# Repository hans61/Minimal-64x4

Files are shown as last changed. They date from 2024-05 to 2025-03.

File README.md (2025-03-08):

# MY Games for the Minimal 64x4

My converted games from Minimal 64
The games 2048, sokoban, loderunner and atomix were automatically generated from the Minimal64 sources.

## Notice

I separated the hardware and software. The hardware can now be found here:
https://github.com/hans61/Minimal-64x4-Expansion

The Minimal 64x4 Home Computer by Slu4 can be found here:
https://github.com/slu4coder/Minimal-64x4-Home-Computer

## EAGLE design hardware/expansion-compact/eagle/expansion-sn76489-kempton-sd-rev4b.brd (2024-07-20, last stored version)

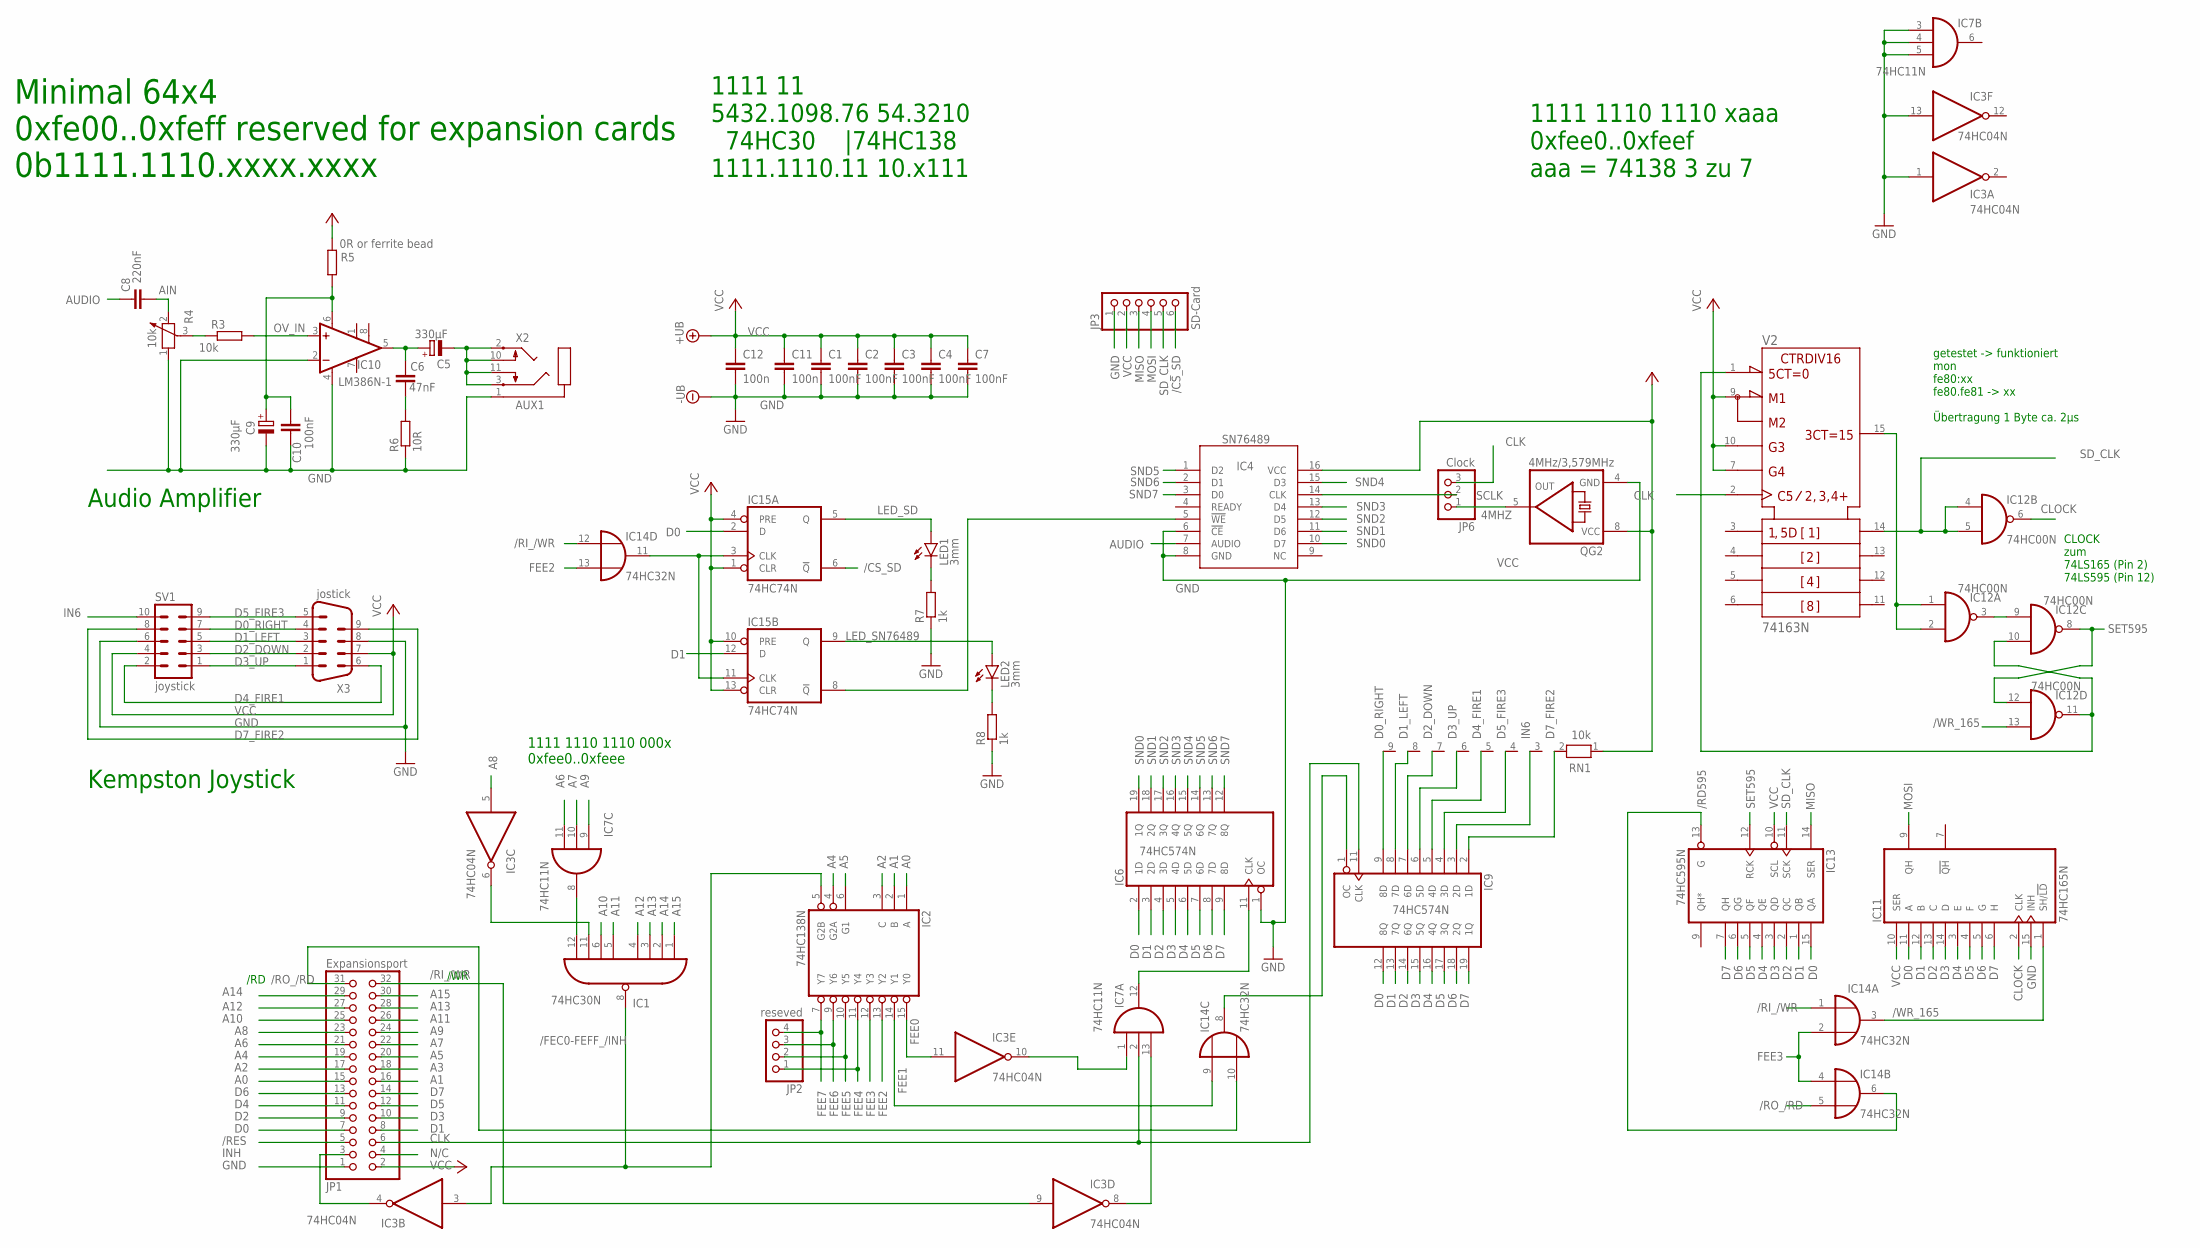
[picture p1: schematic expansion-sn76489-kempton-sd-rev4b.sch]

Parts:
C1, C2, C3, C4, C7, C10: 100nF; C050-025X075
C5, C9: 330µF; E2,5-7
C6: 47nF; C050-025X075
C8: 220nF; C050-025X075
C11, C12: 100n; C050-025X075
IC1: 74HC30N; DIL14
IC2: 74HC138N; DIL16
IC3: 74HC04N; DIL14
IC4: SN76489; ALEX-PARTS_DIL16
IC6, IC9: 74HC574N; DIL20
IC7: 74HC11N; DIL14
IC10: LM386N-1; DIL08
IC11: 74HC165N; DIL16
IC12: 74HC00N; DIL14
IC13: 74HC595N; DIL16
IC14: 74HC32N; DIL14
IC15: 74HC74N; DIL14
JP1: Expansionsport; 2X16
JP2: reseved; 1X04
JP3: SD-Card; 1X06
JP6: Clock; 1X03
LED1, LED2: 3mm; LED3MM
QG2: 4MHz/3,579MHz; DIL08S
R3: 10k; 0207/10
R4: 10k; PT-10S
R5: 0R or ferrite bead; 0207/10
R6: 10R; 0207/10
R7, R8: 1k; 0207/10
RN1: 10k; RN-9
SV1: joystick; ML10
V2: 74163N; DIL16
X2: AUX1; SJ1-352XN
X3: jostick; 182-009-MALE

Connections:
4MHZ: JP6.1, QG2.5 (OUT)
/CS_SD: IC15.6 (!Q), JP3.6
/FEC0-FEFF_/INH: IC1.8 (O), IC2.5 (G2B), IC3.3 (I)
/RD595: IC13.13 (G), IC14.6 (O)
/RES: JP1.5
/RI_/WR: IC3.9 (I), IC14.1 (I0), IC14.12 (I0), JP1.32
/RO_/RD: IC14.5 (I1), IC14.10 (I1), JP1.31
/WR_165: IC11.1 (SH/!LD), IC12.13 (I1), IC14.3 (O)
A0: IC2.1 (A), JP1.15
A1: IC2.2 (B), JP1.16
A2: IC2.3 (C), JP1.17
A3: JP1.18
A4: IC2.4 (G2A), JP1.19
A5: IC2.6 (G1), JP1.20
A6: IC7.11 (I2), JP1.21
A7: IC7.10 (I1), JP1.22
A8: IC3.5 (I), JP1.23
A9: IC7.9 (I0), JP1.24
A10: IC1.6 (I5), JP1.25
A11: IC1.5 (I4), JP1.26
A12: IC1.4 (I3), JP1.27
A13: IC1.3 (I2), JP1.28
A14: IC1.2 (I1), JP1.29
A15: IC1.1 (I0), JP1.30
AIN: C8.2, R4.2
AUDIO: C8.1, IC4.7 (AUDIO)
AUXOUT1: C5.-, X2.2, X2.3, X2.10, X2.11
AVCC: C9.+, C10.1, IC10.6 (VS), R5.1
CLK: IC7.2 (I1), IC9.11 (CLK), JP1.6, JP6.3, V2.2 (CLK)
CLOCK: IC11.2 (CLK), IC12.6 (O)
D0: IC6.2 (1D), IC9.12 (8Q), IC11.11 (A), IC13.15 (QA), IC15.2 (D), JP1.7
D0_RIGHT: IC9.9 (8D), RN1.9, SV1.7, X3.4
D1: IC6.3 (2D), IC9.13 (7Q), IC11.12 (B), IC13.1 (QB), IC15.12 (D), JP1.8
D1_LEFT: IC9.8 (7D), RN1.8, SV1.5, X3.3
D2: IC6.4 (3D), IC9.14 (6Q), IC11.13 (C), IC13.2 (QC), JP1.9
D2_DOWN: IC9.7 (6D), RN1.7, SV1.3, X3.2
D3: IC6.5 (4D), IC9.15 (5Q), IC11.14 (D), IC13.3 (QD), JP1.10
D3_UP: IC9.6 (5D), RN1.6, SV1.1, X3.1
D4: IC6.6 (5D), IC9.16 (4Q), IC11.3 (E), IC13.4 (QE), JP1.11
D4_FIRE1: IC9.5 (4D), RN1.5, SV1.2, X3.6
D5: IC6.7 (6D), IC9.17 (3Q), IC11.4 (F), IC13.5 (QF), JP1.12
D5_FIRE3: IC9.4 (3D), RN1.4, SV1.9, X3.5
D6: IC6.8 (7D), IC9.18 (2Q), IC11.5 (G), IC13.6 (QG), JP1.13
D7: IC6.9 (8D), IC9.19 (1Q), IC11.6 (H), IC13.7 (QH), JP1.14
D7_FIRE2: IC9.2 (1D), RN1.2, SV1.8, X3.9
FEE0: IC2.15 (Y0), IC3.11 (I)
FEE1: IC2.14 (Y1), IC14.9 (I0)
FEE2: IC2.13 (Y2), IC14.13 (I1)
FEE3: IC2.12 (Y3), IC14.2 (I1), IC14.4 (I0)
FEE4: IC2.11 (Y4), JP2.1
FEE5: IC2.10 (Y5), JP2.2
FEE6: IC2.9 (Y6), JP2.3
FEE7: IC2.7 (Y7), JP2.4
GND: C1.2, C2.2, C3.2, C4.2, C7.2, C9.-, C10.2, C11.2, C12.2, IC1.7 (GND), IC2.8 (GND), IC3.1 (I), IC3.7 (GND), IC3.13 (I), IC4.6 (!CE), IC4.8 (GND), IC6.1 (OC), IC6.10 (GND), IC7.3 (I0), IC7.4 (I1), IC7.5 (I2), IC7.7 (GND), IC9.10 (GND), IC10.2 (-IN), IC10.4 (GND), IC11.8 (GND), IC11.15 (INH), IC12.7 (GND), IC13.8 (GND), IC14.7 (GND), IC15.7 (GND), JP1.1, JP3.1, QG2.4 (GND), R4.1, R6.1, R7.1, R8.1, SV1.6, V2.8 (-UB), X2.1, X3.8
IN6: IC9.3 (2D), RN1.3, SV1.10
INH: IC3.4 (O), JP1.3
INPUT_EN: IC9.1 (OC), IC14.8 (O)
LED_SD: IC15.5 (Q), LED1.A
LED_SN76489: IC15.9 (Q), LED2.A
MISO: IC13.14 (SER), JP3.3
MOSI: IC11.9 (QH), JP3.4
unnamed: LED2.K (C), R8.2
unnamed: IC3.10 (O), IC7.1 (I0)
unnamed: IC1.12 (I7), IC7.8 (O)
unnamed: C6.2, R6.2
unnamed: IC12.1 (I0), IC12.2 (I1), V2.15 (RCO)
unnamed: R3.1, R4.3
unnamed: IC12.10 (I1), IC12.11 (O), V2.1 (!CLR)
unnamed: IC12.3 (O), IC12.9 (I0)
unnamed: IC14.11 (O), IC15.3 (CLK), IC15.11 (CLK)
unnamed: LED1.K (C), R7.2
unnamed: IC4.5 (!WE), IC15.8 (!Q)
unnamed: IC1.11 (I6), IC3.6 (O)
N/C: JP1.4
OV_IN: IC10.3 (+IN), R3.2
R2C2C3: C5.+, C6.1, IC10.5 (OUT)
RI_WR: IC3.8 (O), IC7.13 (I2)
SCLK: IC4.14 (CLK), JP6.2
SD_CLK: IC12.4 (I0), IC12.5 (I1), IC13.11 (SCK), JP3.5, V2.14 (QA)
SET595: IC12.8 (O), IC12.12 (I0), IC13.12 (RCK)
SND0: IC4.10 (D7), IC6.19 (1Q)
SND1: IC4.11 (D6), IC6.18 (2Q)
SND2: IC4.12 (D5), IC6.17 (3Q)
SND3: IC4.13 (D4), IC6.16 (4Q)
SND4: IC4.15 (D3), IC6.15 (5Q)
SND5: IC4.1 (D2), IC6.14 (6Q)
SND6: IC4.2 (D1), IC6.13 (7Q)
SND7: IC4.3 (D0), IC6.12 (8Q)
SOUND_EN: IC6.11 (CLK), IC7.12 (O)
VCC: C1.1, C2.1, C3.1, C4.1, C7.1, C11.1, C12.1, IC1.14 (VCC), IC2.16 (VCC), IC3.14 (VCC), IC4.16 (VCC), IC6.20 (VCC), IC7.14 (VCC), IC9.20 (VCC), IC11.10 (SER), IC11.16 (VCC), IC12.14 (VCC), IC13.10 (SCL), IC13.16 (VCC), IC14.14 (VCC), IC15.1 (CLR), IC15.4 (PRE), IC15.10 (PRE), IC15.13 (CLR), IC15.14 (VCC), JP1.2, JP3.2, QG2.8 (VCC), R5.2, RN1.1, SV1.4, V2.7 (ENP), V2.9 (!LOAD), V2.10 (ENT), V2.16 (+UB), X3.7

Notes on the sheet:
1111 1110 1110 xaaa 0xfee0..0xfeef aaa = 74138 3 zu 7
1111 1110 1110 000x 0xfee0..0xfeee
/WR
/RD
Minimal 64x4 0xfe00..0xfeff reserved for expansion cards 0b1111.1110.xxxx.xxxx
1111 11 5432.1098.76 54.3210 74HC30 |74HC138 1111.1110.11 10.x111
Kempston Joystick
Audio Amplifier
CLOCK zum 74LS165 (Pin 2) 74LS595 (Pin 12)
getestet -> funktioniert mon fe80:xx fe80.fe81 -> xx Übertragung 1 Byte ca. 2µs

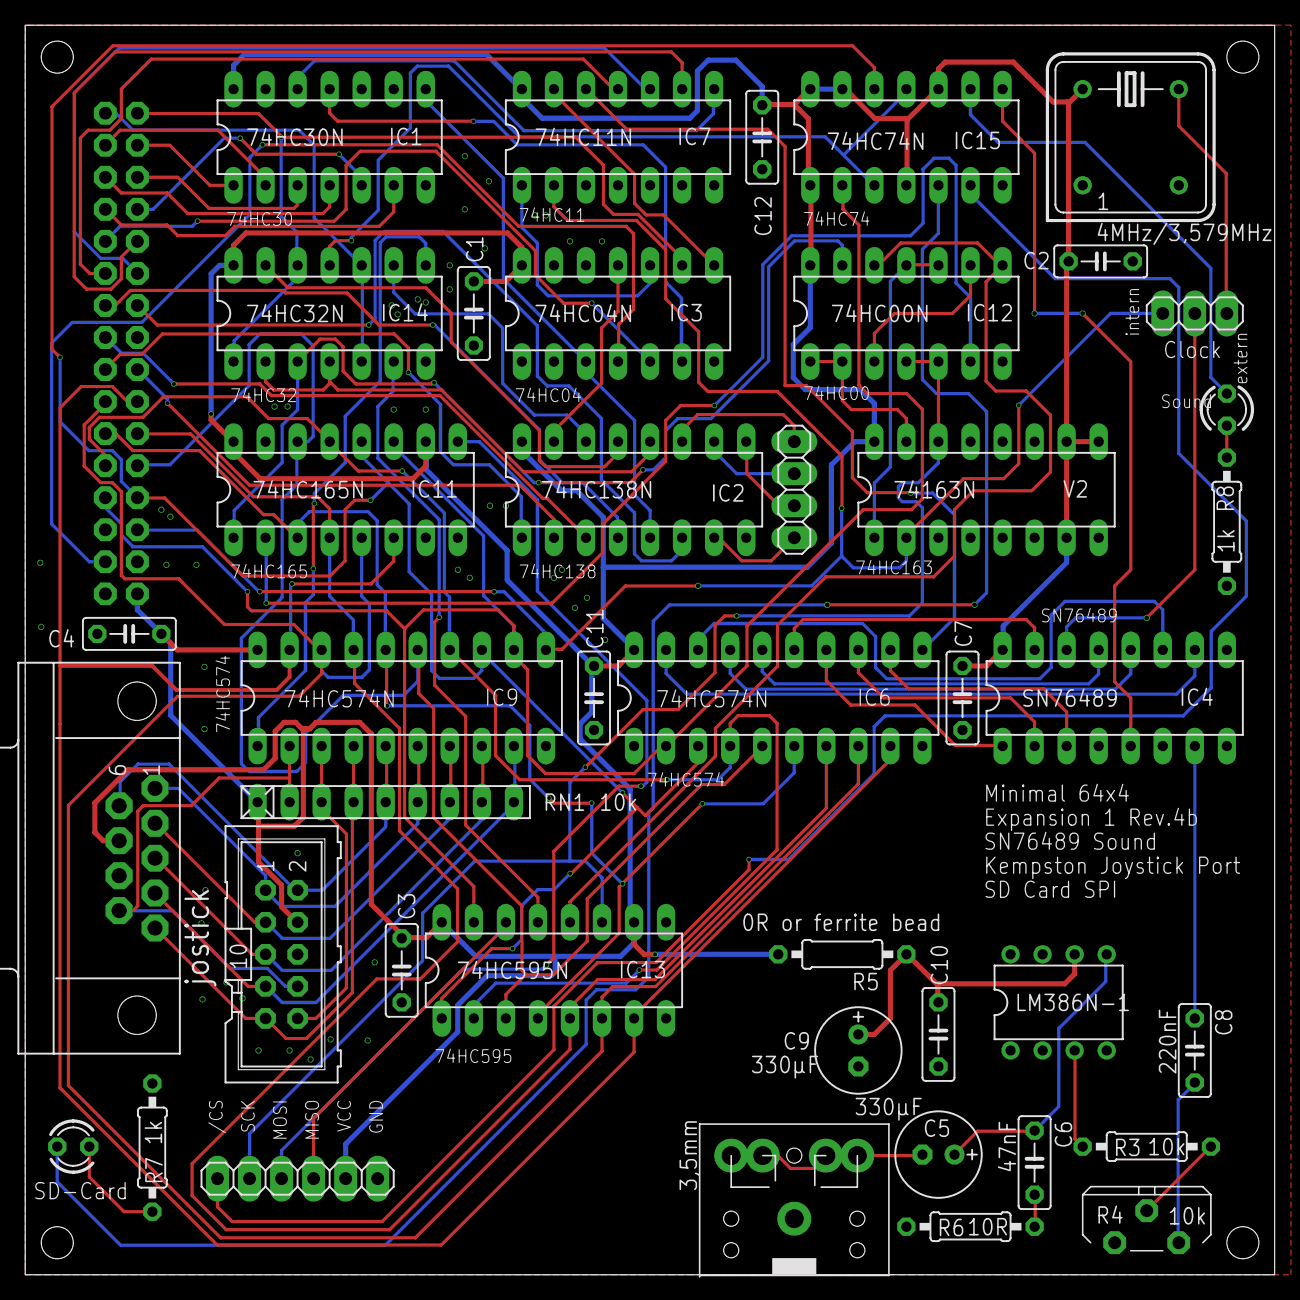
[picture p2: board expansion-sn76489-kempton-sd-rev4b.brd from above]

Board: 2 copper layers, 99.0 x 99.0 mm, 43 parts (1 on the bottom side), 87 nets.

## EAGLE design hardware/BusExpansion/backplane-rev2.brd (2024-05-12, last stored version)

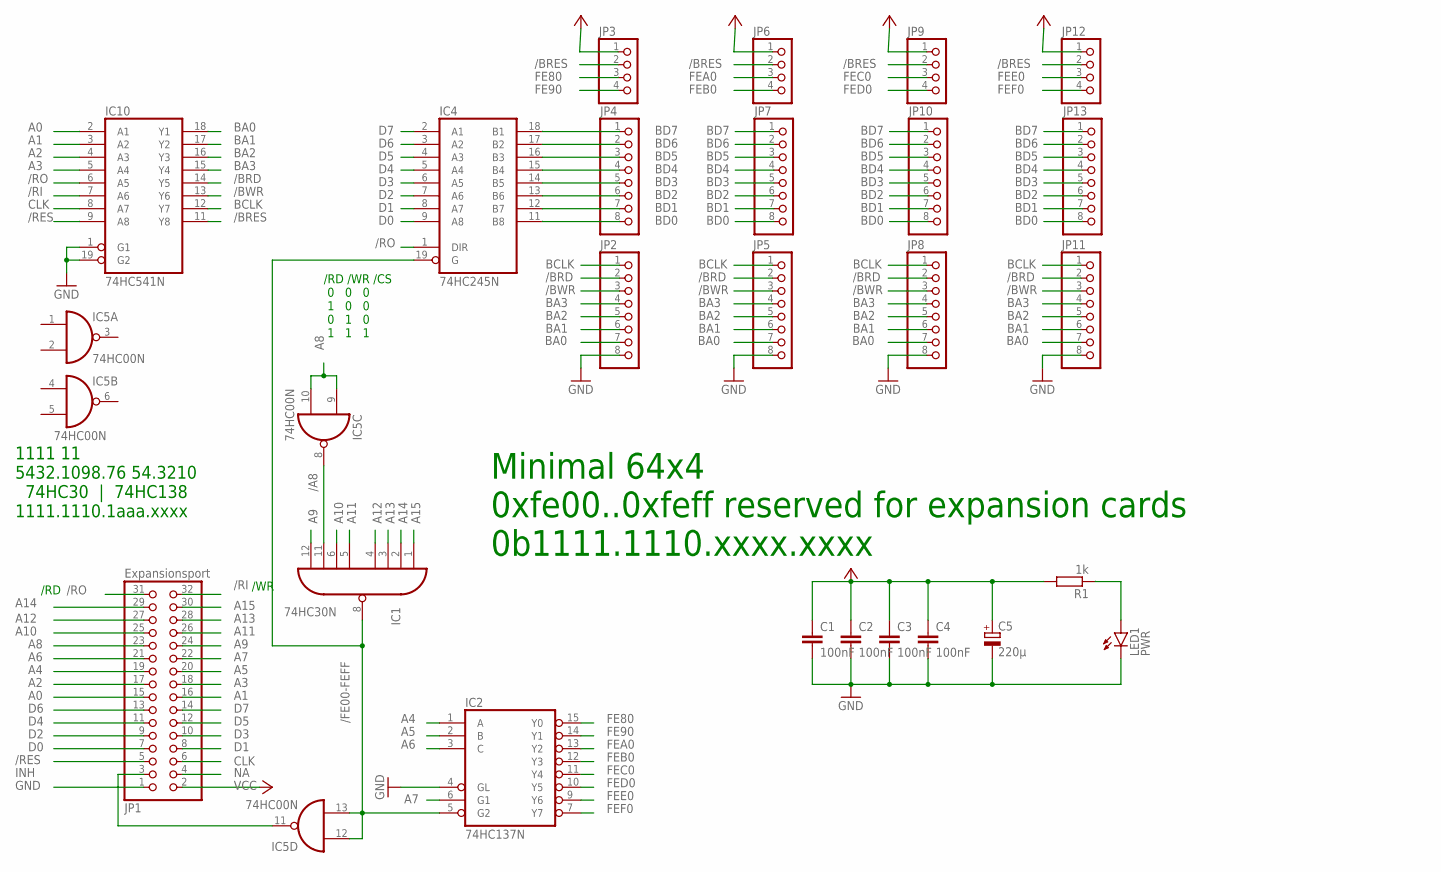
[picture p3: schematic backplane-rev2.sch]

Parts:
C1, C2, C3, C4: 100nF; C050-025X075
C5: 220µ; E3,5-8
IC1: 74HC30N; DIL14
IC2: 74HC137N; DIL16
IC4: 74HC245N; DIL20
IC5: 74HC00N; DIL14
IC10: 74HC541N; DIL20
JP1: Expansionsport; 2X16
JP2, JP4, JP5, JP7, JP8, JP10, JP11, JP13: PINHD-1X8; 1X08
JP3, JP6, JP9, JP12: PINHD-1X4; 1X04
LED1: PWR; LED3MM
R1: 1k; 0207/10

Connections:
/A8: IC1.11 (I6), IC5.8 (O)
/BRD: IC10.14 (Y5), JP2.2, JP5.2, JP8.2, JP11.2
/BRES: IC10.11 (Y8), JP3.2, JP6.2, JP9.2, JP12.2
/BWR: IC10.13 (Y6), JP2.3, JP5.3, JP8.3, JP11.3
/FE00-FEFF: IC1.8 (O), IC2.5 (G2), IC4.19 (G), IC5.12 (I0), IC5.13 (I1)
/RES: IC10.9 (A8), JP1.5
/RI: IC10.7 (A6), JP1.32
/RO: IC4.1 (DIR), IC10.6 (A5), JP1.31
A0: IC10.2 (A1), JP1.15
A1: IC10.3 (A2), JP1.16
A2: IC10.4 (A3), JP1.17
A3: IC10.5 (A4), JP1.18
A4: IC2.1 (A), JP1.19
A5: IC2.2 (B), JP1.20
A6: IC2.3 (C), JP1.21
A7: IC2.6 (G1), JP1.22
A8: IC5.9 (I0), IC5.10 (I1), JP1.23
A9: IC1.12 (I7), JP1.24
A10: IC1.6 (I5), JP1.25
A11: IC1.5 (I4), JP1.26
A12: IC1.4 (I3), JP1.27
A13: IC1.3 (I2), JP1.28
A14: IC1.2 (I1), JP1.29
A15: IC1.1 (I0), JP1.30
BA0: IC10.18 (Y1), JP2.7, JP5.7, JP8.7, JP11.7
BA1: IC10.17 (Y2), JP2.6, JP5.6, JP8.6, JP11.6
BA2: IC10.16 (Y3), JP2.5, JP5.5, JP8.5, JP11.5
BA3: IC10.15 (Y4), JP2.4, JP5.4, JP8.4, JP11.4
BCLK: IC10.12 (Y7), JP2.1, JP5.1, JP8.1, JP11.1
BD0: IC4.11 (B8), JP4.8, JP7.8, JP10.8, JP13.8
BD1: IC4.12 (B7), JP4.7, JP7.7, JP10.7, JP13.7
BD2: IC4.13 (B6), JP4.6, JP7.6, JP10.6, JP13.6
BD3: IC4.14 (B5), JP4.5, JP7.5, JP10.5, JP13.5
BD4: IC4.15 (B4), JP4.4, JP7.4, JP10.4, JP13.4
BD5: IC4.16 (B3), JP4.3, JP7.3, JP10.3, JP13.3
BD6: IC4.17 (B2), JP4.2, JP7.2, JP10.2, JP13.2
BD7: IC4.18 (B1), JP4.1, JP7.1, JP10.1, JP13.1
CLK: IC10.8 (A7), JP1.6
D0: IC4.9 (A8), JP1.7
D1: IC4.8 (A7), JP1.8
D2: IC4.7 (A6), JP1.9
D3: IC4.6 (A5), JP1.10
D4: IC4.5 (A4), JP1.11
D5: IC4.4 (A3), JP1.12
D6: IC4.3 (A2), JP1.13
D7: IC4.2 (A1), JP1.14
FE80: IC2.15 (Y0), JP3.3
FE90: IC2.14 (Y1), JP3.4
FEA0: IC2.13 (Y2), JP6.3
FEB0: IC2.12 (Y3), JP6.4
FEC0: IC2.11 (Y4), JP9.3
FED0: IC2.10 (Y5), JP9.4
FEE0: IC2.9 (Y6), JP12.3
FEF0: IC2.7 (Y7), JP12.4
GND: C1.2, C2.2, C3.2, C4.2, C5.-, IC1.7 (GND), IC2.4 (GL), IC2.8 (GND), IC4.10 (GND), IC5.7 (GND), IC10.1 (G1), IC10.10 (GND), IC10.19 (G2), JP1.1, JP2.8, JP5.8, JP8.8, JP11.8, LED1.K (C)
INH: IC5.11 (O), JP1.3
unnamed: LED1.A, R1.1
NA: JP1.4
VCC: C1.1, C2.1, C3.1, C4.1, C5.+, IC1.14 (VCC), IC2.16 (VCC), IC4.20 (VCC), IC5.14 (VCC), IC10.20 (VCC), JP1.2, JP3.1, JP6.1, JP9.1, JP12.1, R1.2

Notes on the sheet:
/WR
/RD
Minimal 64x4 0xfe00..0xfeff reserved for expansion cards 0b1111.1110.xxxx.xxxx
1111 11 5432.1098.76 54.3210 74HC30 | 74HC138 1111.1110.1aaa.xxxx
/RD /WR /CS 0 0 0 1 0 0 0 1 0 1 1 1

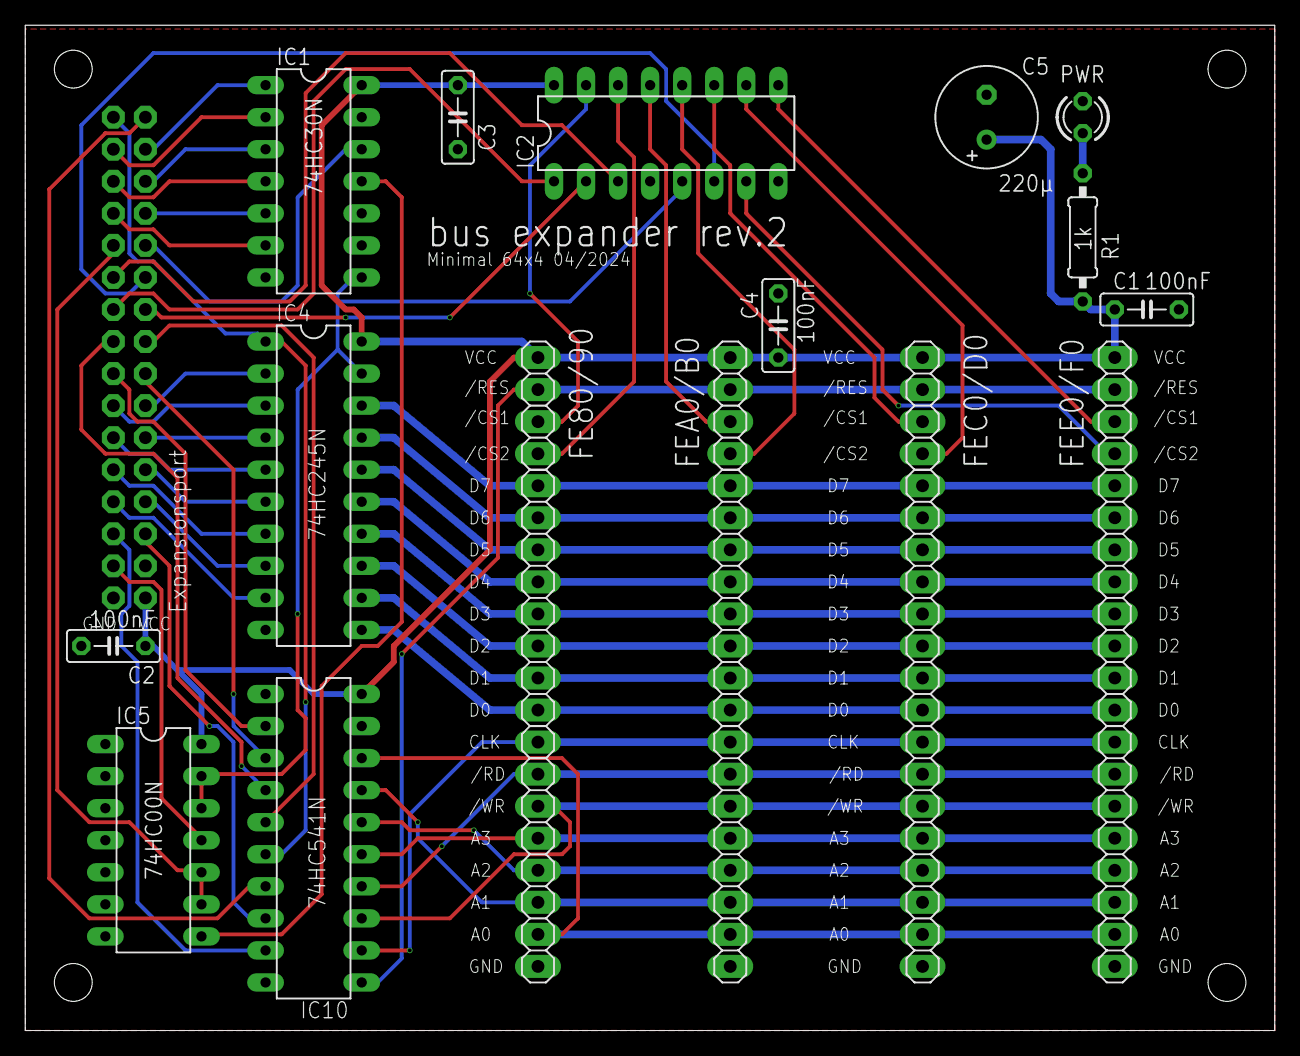
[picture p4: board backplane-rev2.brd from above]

Board: 2 copper layers, 99.0 x 79.7 mm, 25 parts (1 on the bottom side), 58 nets.

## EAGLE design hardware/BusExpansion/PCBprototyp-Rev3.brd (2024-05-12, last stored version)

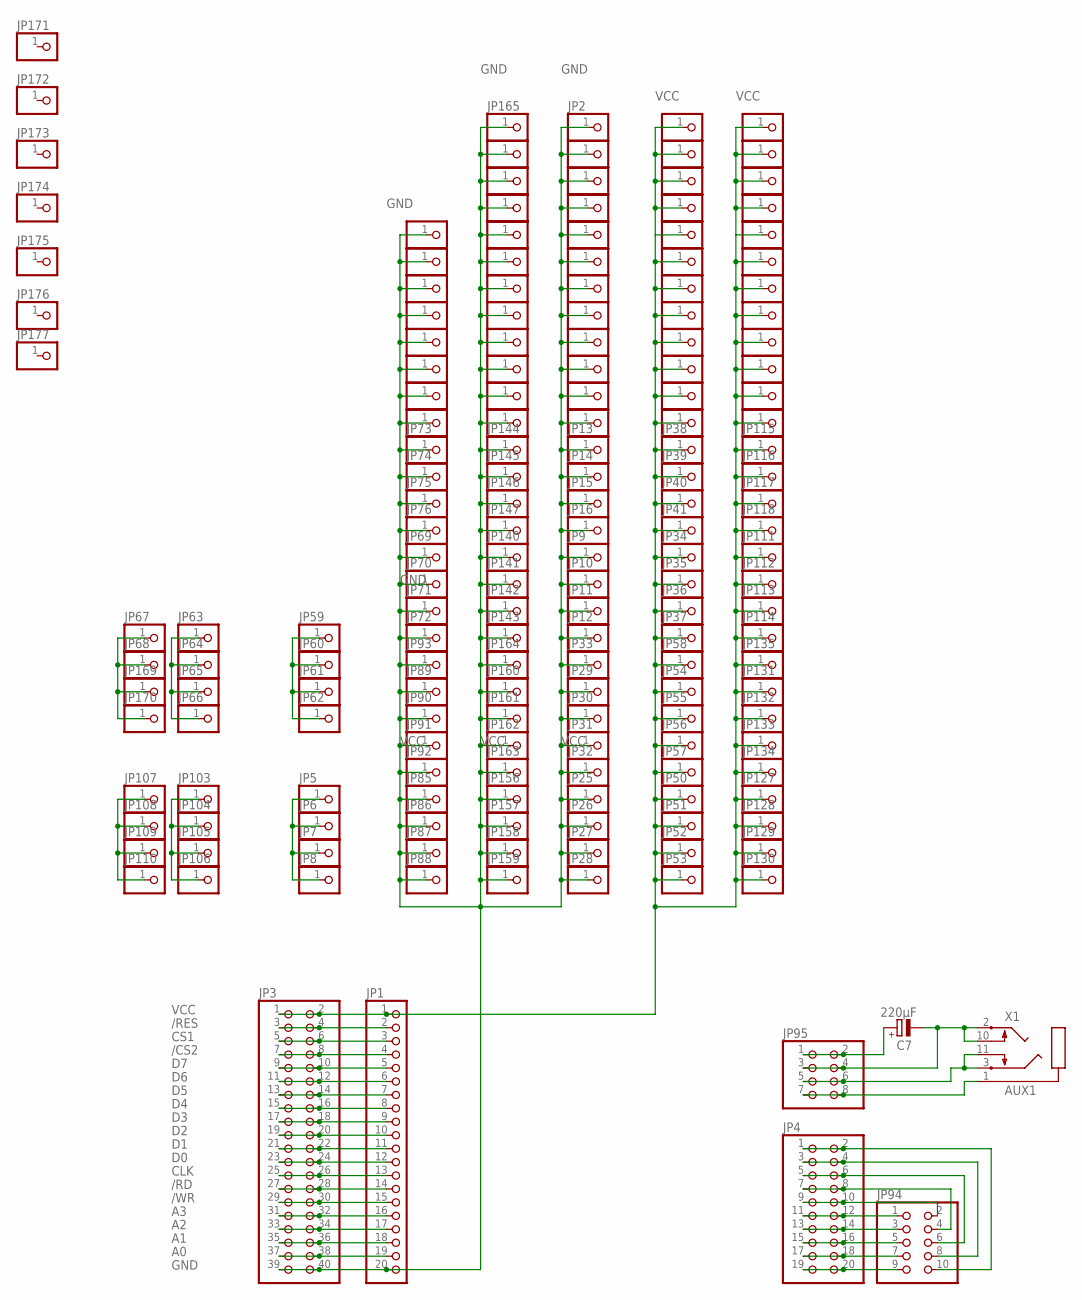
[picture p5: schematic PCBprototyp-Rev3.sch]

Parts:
C7: 220µF; E2,5-7
JP1: PINHD-1X20; 1X20
JP2, JP5, JP6, JP7, JP8, JP9, JP10, JP11, JP12, JP13, JP14, JP15, JP16, JP17, JP18, JP19, JP20, JP21, JP22, JP23, JP24, JP25, JP26, JP27, JP28, JP29, JP30, JP31, JP32, JP33, JP34, JP35, JP36, JP37, JP38, JP39, JP40, JP41, JP42, JP43, JP44, JP45, JP46, JP47, JP48, JP49, JP50, JP51, JP52, JP53, JP54, JP55, JP56, JP57, JP58, JP59, JP60, JP61, JP62, JP63, JP64, JP65, JP66, JP67, JP68, JP69, JP70, JP71, JP72, JP73, JP74, JP75, JP76, JP77, JP78, JP79, JP80, JP81, JP82, JP83, JP84, JP85, JP86, JP87, JP88, JP89, JP90, JP91, JP92, JP93, JP96, JP97, JP98, JP99, JP100, JP101, JP102, JP103, JP104, JP105, JP106, JP107, JP108, JP109, JP110, JP111, JP112, JP113, JP114, JP115, JP116, JP117, JP118, JP119, JP120, JP121, JP122, JP123, JP124, JP125, JP126, JP127, JP128, JP129, JP130, JP131, JP132, JP133, JP134, JP135, JP136, JP137, JP138, JP139, JP140, JP141, JP142, JP143, JP144, JP145, JP146, JP147, JP148, JP149, JP150, JP151, JP152, JP153, JP154, JP155, JP156, JP157, JP158, JP159, JP160, JP161, JP162, JP163, JP164, JP165, JP166, JP167, JP168, JP169, JP170, JP171, JP172, JP173, JP174, JP175, JP176, JP177: PINHD-1X1; 1X01
JP3: PINHD-2X20; 2X20
JP4: PINHD-2X10; 2X10
JP94: PINHD-2X5; 2X05
JP95: PINHD-2X4; 2X04
X1: AUX1; SJ1-352XN

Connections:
/CS2: JP1.4, JP3.7, JP3.8
/RD: JP1.14, JP3.27, JP3.28
/RES: JP1.2, JP3.3, JP3.4
/WR: JP1.15, JP3.29, JP3.30
A0: JP1.19, JP3.37, JP3.38
A1: JP1.18, JP3.35, JP3.36
A2: JP1.17, JP3.33, JP3.34
A3: JP1.16, JP3.31, JP3.32
CLK: JP1.13, JP3.25, JP3.26
CS1: JP1.3, JP3.5, JP3.6
D0: JP1.12, JP3.23, JP3.24
D1: JP1.11, JP3.21, JP3.22
D2: JP1.10, JP3.19, JP3.20
D3: JP1.9, JP3.17, JP3.18
D4: JP1.8, JP3.15, JP3.16
D5: JP1.7, JP3.13, JP3.14
D6: JP1.6, JP3.11, JP3.12
D7: JP1.5, JP3.9, JP3.10
GND: JP1.20, JP2.1, JP3.39, JP3.40, JP9.1, JP10.1, JP11.1, JP12.1, JP13.1, JP14.1, JP15.1, JP16.1, JP17.1, JP18.1, JP19.1, JP20.1, JP21.1, JP22.1, JP23.1, JP24.1, JP25.1, JP26.1, JP27.1, JP28.1, JP29.1, JP30.1, JP31.1, JP32.1, JP33.1, JP69.1, JP70.1, JP71.1, JP72.1, JP73.1, JP74.1, JP75.1, JP76.1, JP77.1, JP78.1, JP79.1, JP80.1, JP81.1, JP82.1, JP83.1, JP84.1, JP85.1, JP86.1, JP87.1, JP88.1, JP89.1, JP90.1, JP91.1, JP92.1, JP93.1, JP96.1, JP97.1, JP98.1, JP140.1, JP141.1, JP142.1, JP143.1, JP144.1, JP145.1, JP146.1, JP147.1, JP148.1, JP149.1, JP150.1, JP151.1, JP152.1, JP153.1, JP154.1, JP155.1, JP156.1, JP157.1, JP158.1, JP159.1, JP160.1, JP161.1, JP162.1, JP163.1, JP164.1, JP165.1, JP166.1, JP167.1, JP168.1
unnamed: C7.-, JP95.3, JP95.4, X1.2, X1.10
unnamed: JP95.5, JP95.6, X1.3, X1.11
unnamed: JP95.7, JP95.8, X1.1
unnamed: C7.+, JP95.1, JP95.2
unnamed: JP103.1, JP104.1, JP105.1, JP106.1
unnamed: JP5.1, JP6.1, JP7.1, JP8.1
unnamed: JP59.1, JP60.1, JP61.1, JP62.1
unnamed: JP107.1, JP108.1, JP109.1, JP110.1
unnamed: JP63.1, JP64.1, JP65.1, JP66.1
unnamed: JP67.1, JP68.1, JP169.1, JP170.1
S1: JP4.11, JP4.12, JP94.1
S2: JP4.9, JP4.10, JP94.2
S3: JP4.13, JP4.14, JP94.3
S4: JP4.7, JP4.8, JP94.4
S5: JP4.15, JP4.16, JP94.5
S6: JP4.5, JP4.6, JP94.6
S7: JP4.17, JP4.18, JP94.7
S8: JP4.3, JP4.4, JP94.8
S9: JP4.19, JP4.20, JP94.9
S10: JP4.1, JP4.2, JP94.10
VCC: JP1.1, JP3.1, JP3.2, JP34.1, JP35.1, JP36.1, JP37.1, JP38.1, JP39.1, JP40.1, JP41.1, JP42.1, JP43.1, JP44.1, JP45.1, JP46.1, JP47.1, JP48.1, JP49.1, JP50.1, JP51.1, JP52.1, JP53.1, JP54.1, JP55.1, JP56.1, JP57.1, JP58.1, JP99.1, JP100.1, JP101.1, JP102.1, JP111.1, JP112.1, JP113.1, JP114.1, JP115.1, JP116.1, JP117.1, JP118.1, JP119.1, JP120.1, JP121.1, JP122.1, JP123.1, JP124.1, JP125.1, JP126.1, JP127.1, JP128.1, JP129.1, JP130.1, JP131.1, JP132.1, JP133.1, JP134.1, JP135.1, JP136.1, JP137.1, JP138.1, JP139.1

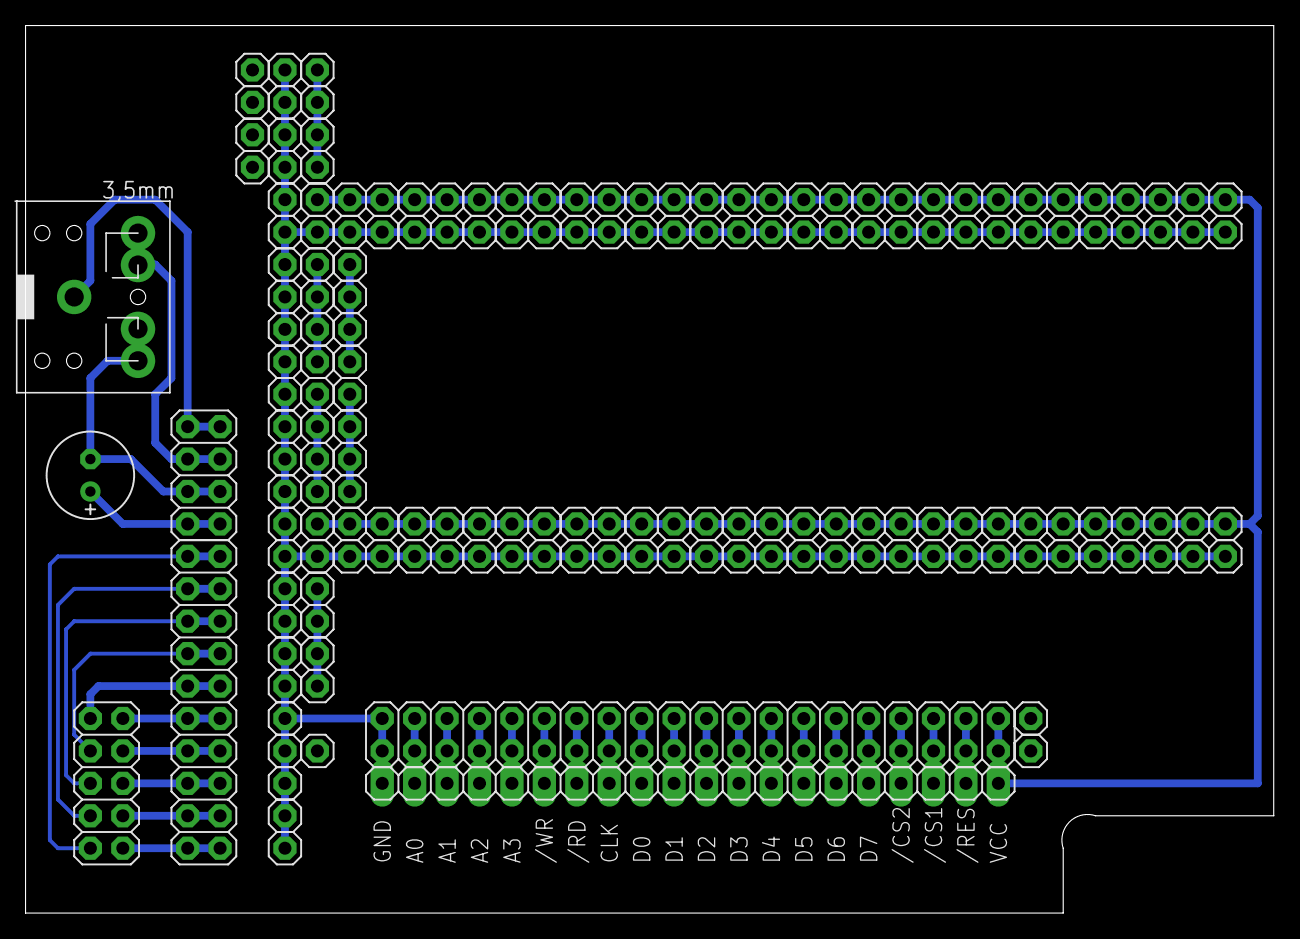
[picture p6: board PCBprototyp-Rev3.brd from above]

Board: 2 copper layers, 97.8 x 69.5 mm, 179 parts (0 on the bottom side), 40 nets.

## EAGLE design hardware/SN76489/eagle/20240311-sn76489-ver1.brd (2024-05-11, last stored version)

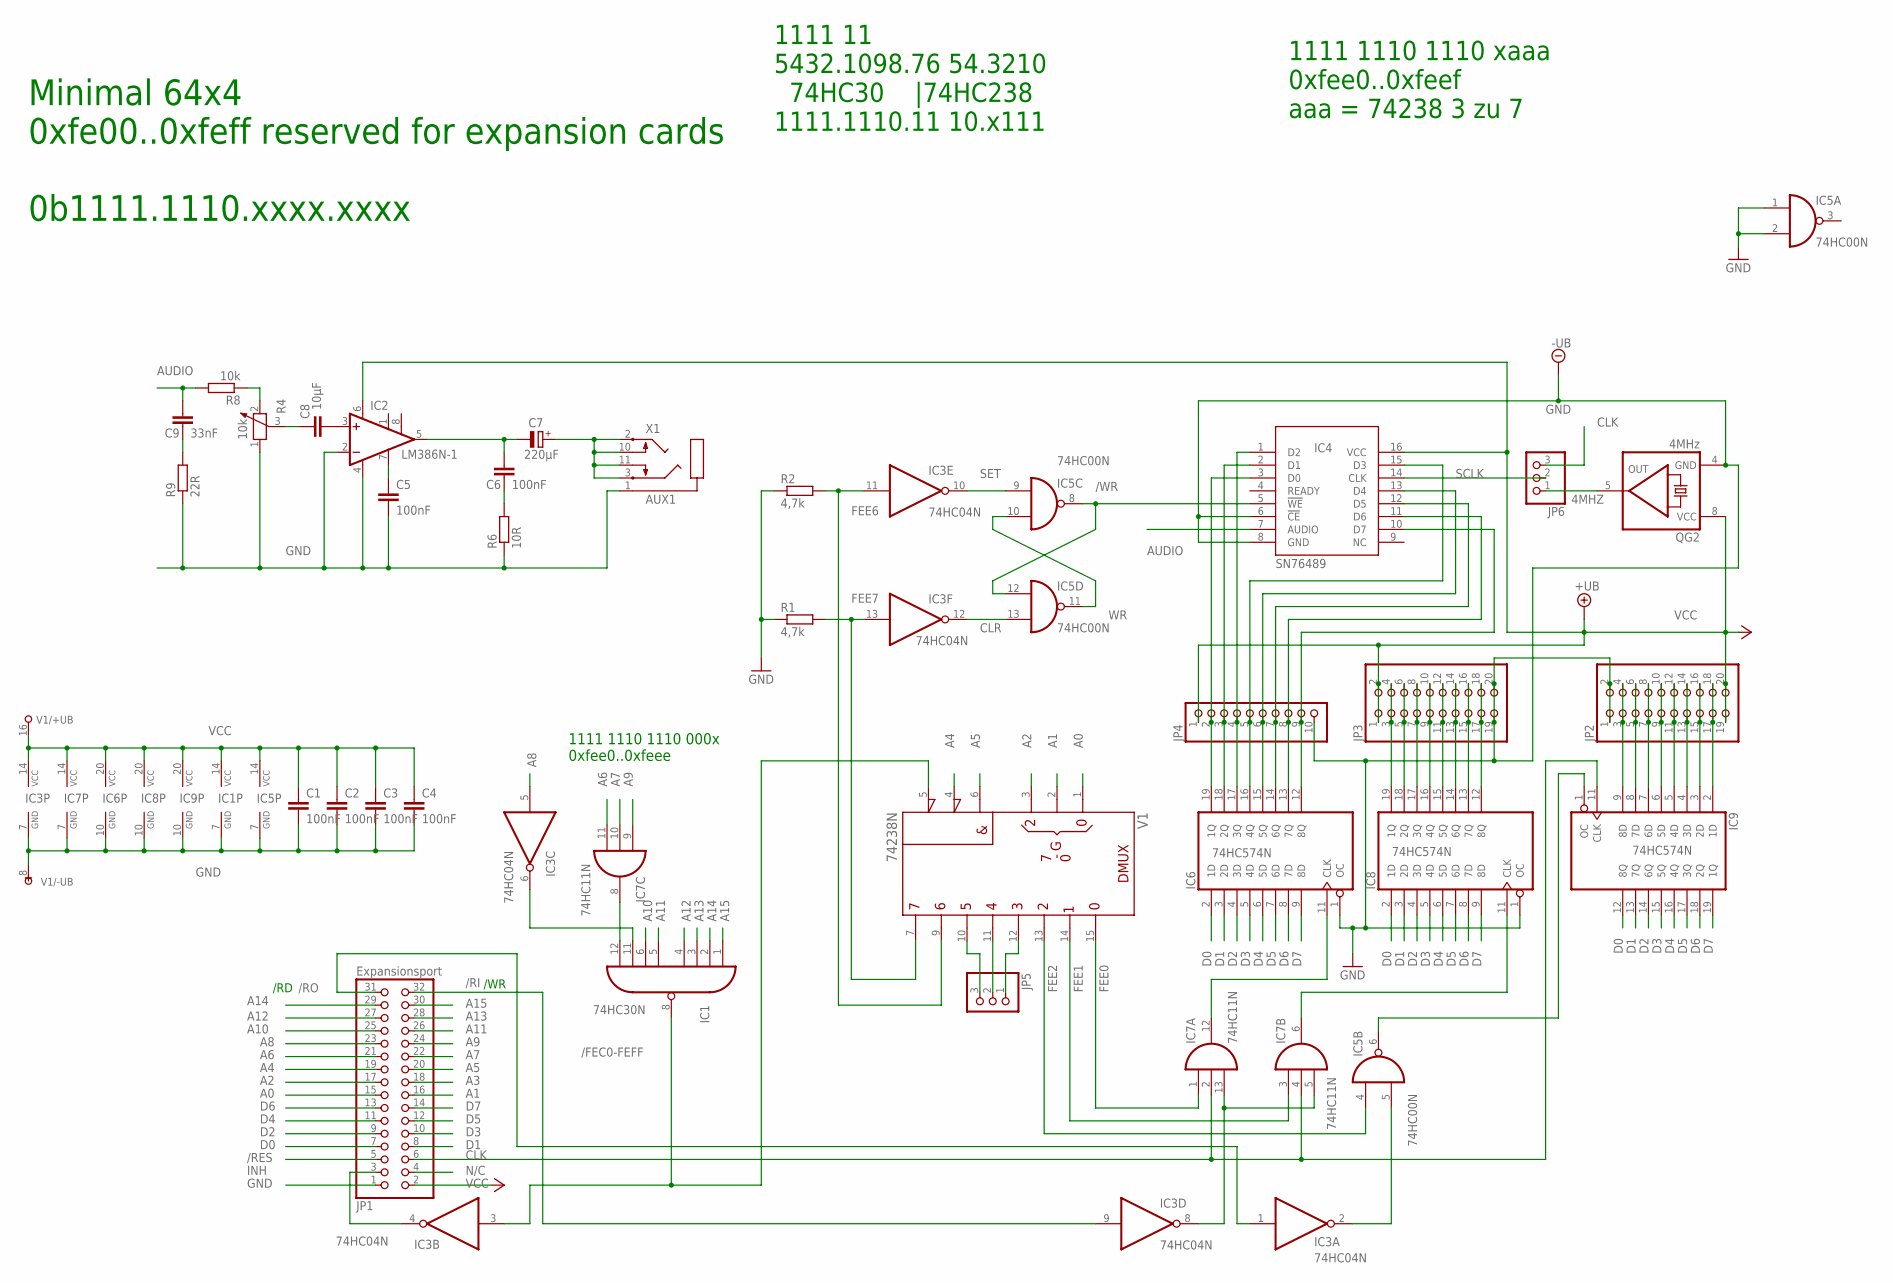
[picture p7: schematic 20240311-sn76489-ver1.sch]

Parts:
C1, C2, C3, C4, C5, C6: 100nF; C050-025X075
C7: 220µF; E2,5-7
C8: 10µF; C050-025X075
C9: 33nF; C050-025X075
IC1: 74HC30N; DIL14
IC2: LM386N-1; DIL08
IC3: 74HC04N; DIL14
IC4: SN76489; ALEX-PARTS_DIL16
IC5: 74HC00N; DIL14
IC6, IC8, IC9: 74HC574N; DIL20
IC7: 74HC11N; DIL14
JP1: Expansionsport; 2X16
JP2, JP3: PINHD-2X10; 2X10
JP4: PINHD-1X10; 1X10
JP5, JP6: PINHD-1X3; 1X03
QG2: 4MHz; DIL08S
R1, R2: 4,7k; 0207/10
R4: 10k; PT-10S
R6: 10R; 0207/10
R8: 10k; 0207/10
R9: 22R; 0207/10
V1: 74238N; DIL16
X1: AUX1; SJ1-352XN

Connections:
4MHZ: JP6.1, QG2.5 (OUT)
/FEC0-FEFF: IC1.8 (O), IC3.3 (I), V1.5 (!G2B)
/RES: JP1.5
/RI: IC3.9 (I), JP1.32
/RO: IC3.1 (I), JP1.31
/WR: IC4.5 (!WE), IC5.8 (O), IC5.12 (I0)
A0: JP1.15, V1.1 (A)
A1: JP1.16, V1.2 (B)
A2: JP1.17, V1.3 (C)
A3: JP1.18
A4: JP1.19, V1.4 (!G2A)
A5: JP1.20, V1.6 (G1)
A6: IC7.11 (I2), JP1.21
A7: IC7.10 (I1), JP1.22
A8: IC3.5 (I), JP1.23
A9: IC7.9 (I0), JP1.24
A10: IC1.6 (I5), JP1.25
A11: IC1.5 (I4), JP1.26
A12: IC1.4 (I3), JP1.27
A13: IC1.3 (I2), JP1.28
A14: IC1.2 (I1), JP1.29
A15: IC1.1 (I0), JP1.30
AUDIO: C9.1, IC4.7 (AUDIO), R8.2
AUXOUT: C7.+, X1.2, X1.3, X1.10, X1.11
CLK: IC7.2 (I1), IC7.4 (I1), IC9.11 (CLK), JP1.6, JP6.3
CLR: IC3.12 (O), IC5.13 (I1)
D0: IC6.2 (1D), IC8.2 (1D), IC9.12 (8Q), JP1.7
D1: IC6.3 (2D), IC8.3 (2D), IC9.13 (7Q), JP1.8
D2: IC6.4 (3D), IC8.4 (3D), IC9.14 (6Q), JP1.9
D3: IC6.5 (4D), IC8.5 (4D), IC9.15 (5Q), JP1.10
D4: IC6.6 (5D), IC8.6 (5D), IC9.16 (4Q), JP1.11
D5: IC6.7 (6D), IC8.7 (6D), IC9.17 (3Q), JP1.12
D6: IC6.8 (7D), IC8.8 (7D), IC9.18 (2Q), JP1.13
D7: IC6.9 (8D), IC8.9 (8D), IC9.19 (1Q), JP1.14
FEE0: IC7.1 (I0), V1.15 (Y0)
FEE1: IC7.3 (I0), V1.14 (Y1)
FEE2: IC5.4 (I0), V1.13 (Y2)
FEE3: JP5.1, V1.12 (Y3)
FEE4: JP5.2, V1.11 (Y4)
FEE5: JP5.3, V1.10 (Y5)
FEE6: IC3.11 (I), R2.2, V1.9 (Y6)
FEE7: IC3.13 (I), R1.2, V1.7 (Y7)
GND: C1.2, C2.2, C3.2, C4.2, C5.2, IC1.7 (GND), IC2.2 (-IN), IC2.4 (GND), IC3.7 (GND), IC4.6 (!CE), IC4.8 (GND), IC5.1 (I0), IC5.2 (I1), IC5.7 (GND), IC6.1 (OC), IC6.10 (GND), IC7.7 (GND), IC8.1 (OC), IC8.10 (GND), IC9.10 (GND), JP1.1, JP2.1, JP2.2, JP3.19, JP3.20, JP4.10, QG2.4 (GND), R1.1, R2.1, R4.1, R6.1, R9.1, V1.8 (-UB), X1.1
IN0: IC9.9 (8D), JP2.3, JP2.4
IN1: IC9.8 (7D), JP2.5, JP2.6
IN2: IC9.7 (6D), JP2.7, JP2.8
IN3: IC9.6 (5D), JP2.9, JP2.10
IN4: IC9.5 (4D), JP2.11, JP2.12
IN5: IC9.4 (3D), JP2.13, JP2.14
IN6: IC9.3 (2D), JP2.15, JP2.16
IN7: IC9.2 (1D), JP2.17, JP2.18
INH: IC3.4 (O), JP1.3
LM5: C6.1, C7.-, IC2.5 (OUT)
LM7: C5.1, IC2.7 (BYPASS)
unnamed: IC3.2 (O), IC5.5 (I1)
unnamed: IC1.12 (I7), IC7.8 (O)
unnamed: IC6.11 (CLK), IC7.12 (O)
unnamed: IC1.11 (I6), IC3.6 (O)
unnamed: IC3.8 (O), IC7.5 (I2), IC7.13 (I2)
unnamed: IC7.6 (O), IC8.11 (CLK)
unnamed: IC5.6 (O), IC9.1 (OC)
unnamed: C6.2, R6.2
unnamed: C8.2, IC2.3 (+IN)
unnamed: C9.2, R9.2
unnamed: R4.2, R8.1
unnamed: C8.1, R4.3
N/C: JP1.4
OUT0: IC8.19 (1Q), JP3.3, JP3.4
OUT1: IC8.18 (2Q), JP3.5, JP3.6
OUT2: IC8.17 (3Q), JP3.7, JP3.8
OUT3: IC8.16 (4Q), JP3.9, JP3.10
OUT4: IC8.15 (5Q), JP3.11, JP3.12
OUT5: IC8.14 (6Q), JP3.13, JP3.14
OUT6: IC8.13 (7Q), JP3.15, JP3.16
OUT7: IC8.12 (8Q), JP3.17, JP3.18
SCLK: IC4.14 (CLK), JP6.2
SET: IC3.10 (O), IC5.9 (I0)
SND0: IC4.3 (D0), IC6.19 (1Q), JP4.2
SND1: IC4.2 (D1), IC6.18 (2Q), JP4.3
SND2: IC4.1 (D2), IC6.17 (3Q), JP4.4
SND3: IC4.15 (D3), IC6.16 (4Q), JP4.5
SND4: IC4.13 (D4), IC6.15 (5Q), JP4.6
SND5: IC4.12 (D5), IC6.14 (6Q), JP4.7
SND6: IC4.11 (D6), IC6.13 (7Q), JP4.8
SND7: IC4.10 (D7), IC6.12 (8Q), JP4.9
VCC: C1.1, C2.1, C3.1, C4.1, IC1.14 (VCC), IC2.6 (VS), IC3.14 (VCC), IC4.16 (VCC), IC5.14 (VCC), IC6.20 (VCC), IC7.14 (VCC), IC8.20 (VCC), IC9.20 (VCC), JP1.2, JP2.19, JP2.20, JP3.1, JP3.2, JP4.1, QG2.8 (VCC), V1.16 (+UB)
WR: IC5.10 (I1), IC5.11 (O)

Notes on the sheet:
1111 1110 1110 xaaa 0xfee0..0xfeef aaa = 74238 3 zu 7
1111 1110 1110 000x 0xfee0..0xfeee
/WR
/RD
Minimal 64x4 0xfe00..0xfeff reserved for expansion cards 0b1111.1110.xxxx.xxxx
1111 11 5432.1098.76 54.3210 74HC30 |74HC238 1111.1110.11 10.x111

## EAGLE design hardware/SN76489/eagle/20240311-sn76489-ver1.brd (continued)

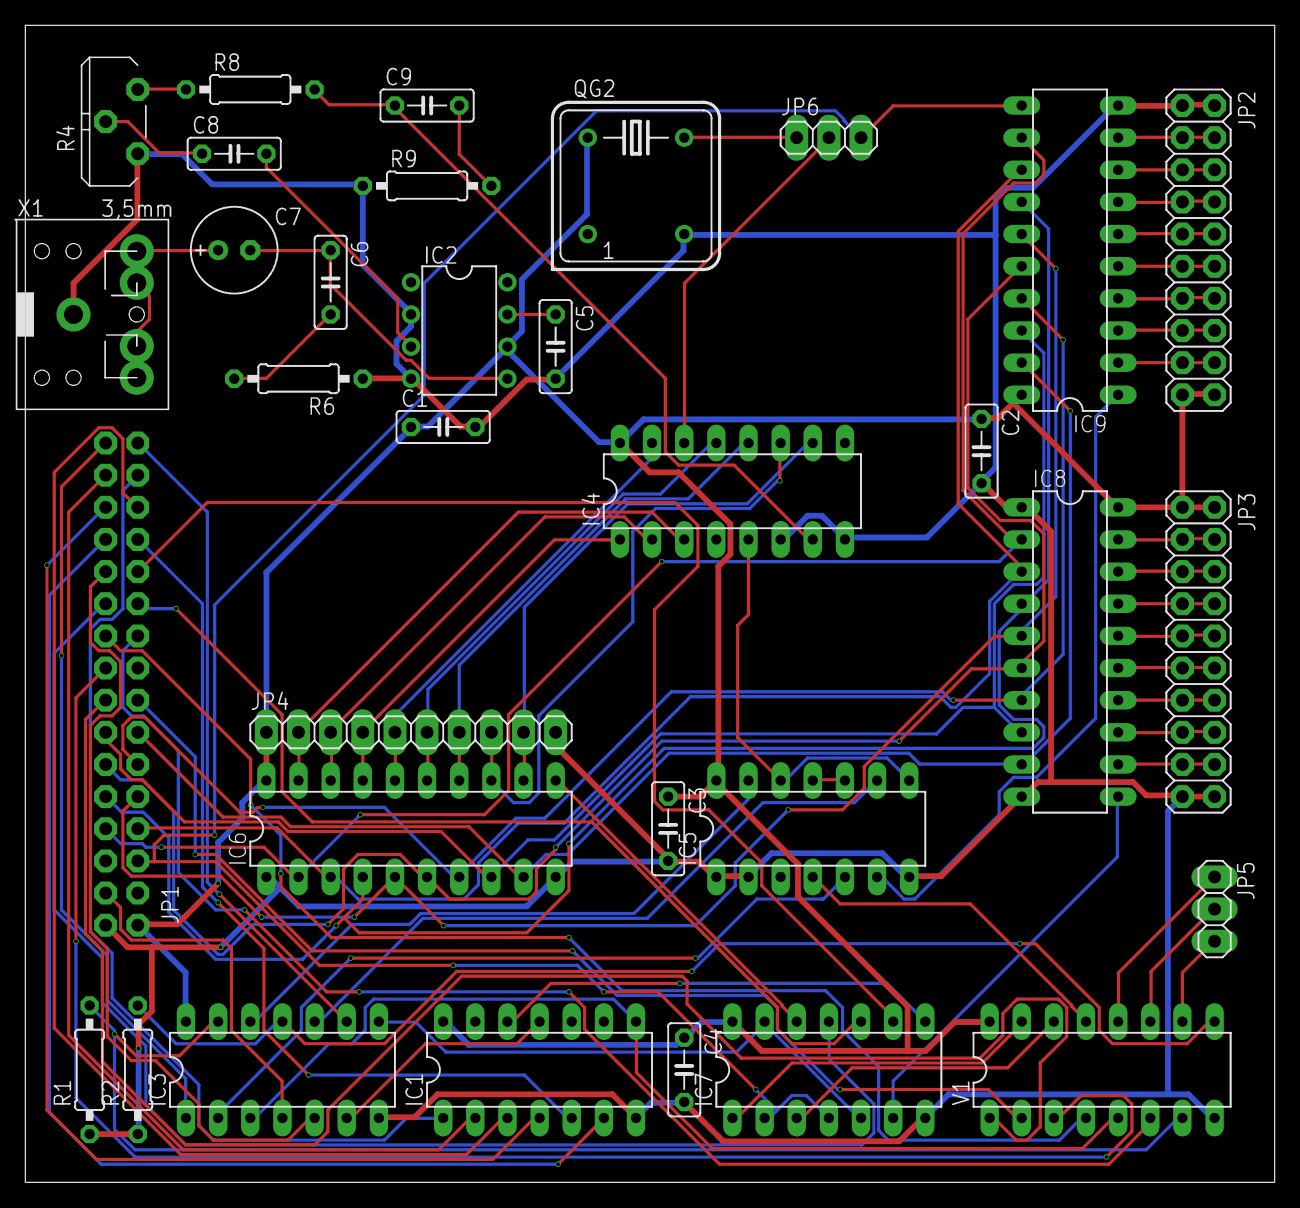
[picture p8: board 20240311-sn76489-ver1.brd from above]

Board: 2 copper layers, 98.7 x 91.4 mm, 33 parts (1 on the bottom side), 84 nets.

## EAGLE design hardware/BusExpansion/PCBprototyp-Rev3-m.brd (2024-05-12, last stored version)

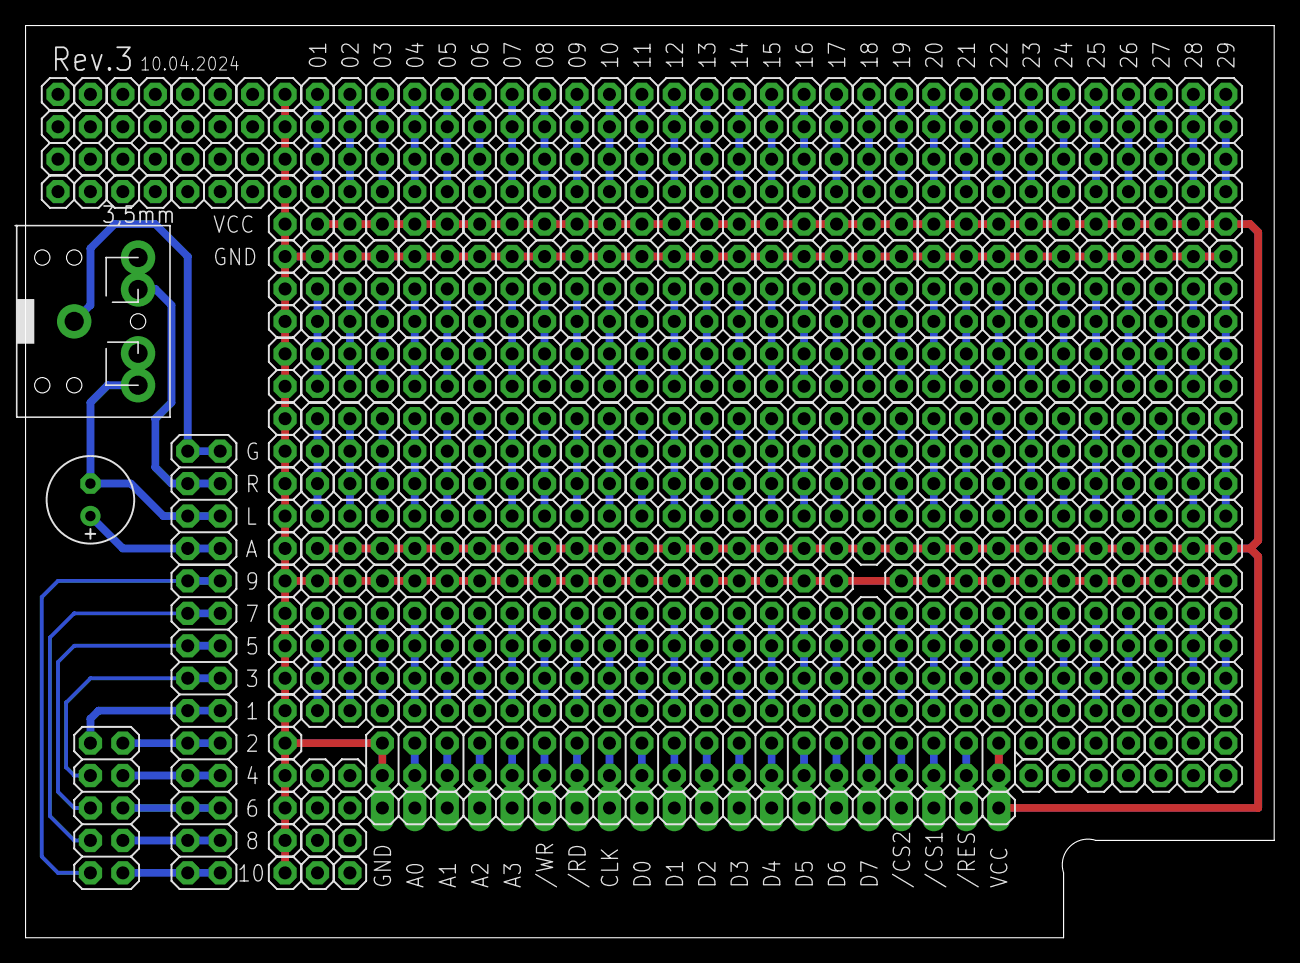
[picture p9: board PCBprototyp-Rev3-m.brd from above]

Board: 2 copper layers, 97.8 x 71.4 mm, 661 parts (0 on the bottom side), 150 nets.

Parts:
C7: 220µF; E2,5-7
JP1: 1X20
JP2, JP5, JP6, JP7, JP8, JP9, JP10, JP11, JP12, JP13, JP14, JP15, JP16, JP17, JP18, JP19, JP20, JP21, JP22, JP23, JP24, JP26, JP27, JP28, JP29, JP30, JP31, JP32, JP33, JP34, JP35, JP36, JP37, JP38, JP39, JP40, JP41, JP42, JP43, JP44, JP45, JP46, JP47, JP48, JP49, JP50, JP51, JP52, JP53, JP54, JP55, JP56, JP57, JP58, JP59, JP60, JP61, JP62, JP63, JP64, JP65, JP66, JP67, JP68, JP69, JP70, JP71, JP72, JP73, JP74, JP75, JP76, JP77, JP78, JP79, JP80, JP81, JP82, JP83, JP84, JP85, JP86, JP87, JP88, JP89, JP90, JP91, JP92, JP93, JP96, JP97, JP98, JP99, JP100, JP101, JP102, JP103, JP104, JP105, JP106, JP107, JP108, JP109, JP110, JP111, JP112, JP113, JP114, JP115, JP116, JP117, JP118, JP119, JP120, JP121, JP122, JP123, JP124, JP125, JP126, JP127, JP128, JP129, JP130, JP131, JP132, JP133, JP134, JP135, JP136, JP137, JP138, JP139, JP140, JP141, JP142, JP143, JP144, JP145, JP146, JP147, JP148, JP149, JP150, JP151, JP152, JP153, JP154, JP155, JP156, JP157, JP158, JP159, JP160, JP161, JP162, JP163, JP164, JP165, JP166, JP167, JP168, JP169, JP170, JP171, JP172, JP173, JP174, JP175, JP176, JP177, JP178, JP179, JP180, JP181, JP182, JP183, JP184, JP185, JP186, JP187, JP188, JP189, JP190, JP191, JP192, JP193, JP194, JP195, JP196, JP197, JP198, JP199, JP200, JP201, JP202, JP203, JP204, JP205, JP206, JP207, JP208, JP209, JP210, JP211, JP212, JP213, JP214, JP215, JP216, JP217, JP218, JP219, JP220, JP221, JP222, JP223, JP224, JP225, JP226, JP227, JP228, JP229, JP230, JP231, JP232, JP233, JP234, JP235, JP236, JP237, JP238, JP239, JP240, JP241, JP242, JP243, JP244, JP245, JP246, JP247, JP248, JP249, JP250, JP251, JP252, JP253, JP254, JP255, JP256, JP257, JP258, JP259, JP260, JP261, JP262, JP263, JP264, JP265, JP266, JP267, JP268, JP269, JP270, JP271, JP272, JP273, JP274, JP275, JP276, JP277, JP278, JP279, JP280, JP281, JP282, JP283, JP284, JP285, JP286, JP287, JP288, JP289, JP290, JP291, JP292, JP293, JP294, JP295, JP296, JP297, JP298, JP299, JP300, JP301, JP302, JP303, JP304, JP305, JP306, JP307, JP308, JP309, JP310, JP311, JP312, JP313, JP314, JP315, JP316, JP317, JP318, JP319, JP320, JP321, JP322, JP323, JP324, JP325, JP326, JP327, JP328, JP329, JP330, JP331, JP332, JP333, JP334, JP335, JP336, JP337, JP338, JP339, JP340, JP341, JP342, JP343, JP344, JP345, JP346, JP347, JP348, JP349, JP350, JP351, JP352, JP353, JP354, JP355, JP356, JP357, JP358, JP359, JP360, JP361, JP362, JP363, JP364, JP365, JP366, JP367, JP368, JP369, JP370, JP371, JP372, JP373, JP374, JP375, JP376, JP377, JP378, JP379, JP380, JP381, JP382, JP383, JP384, JP385, JP386, JP387, JP388, JP389, JP390, JP391, JP392, JP393, JP394, JP395, JP396, JP397, JP398, JP399, JP400, JP401, JP402, JP403, JP404, JP405, JP406, JP407, JP408, JP409, JP410, JP411, JP412, JP413, JP414, JP415, JP416, JP417, JP418, JP419, JP420, JP421, JP422, JP423, JP424, JP425, JP426, JP427, JP428, JP429, JP430, JP431, JP432, JP433, JP434, JP435, JP436, JP437, JP438, JP439, JP440, JP441, JP442, JP443, JP444, JP445, JP446, JP447, JP448, JP449, JP450, JP451, JP452, JP453, JP454, JP455, JP456, JP457, JP458, JP459, JP460, JP461, JP462, JP463, JP464, JP465, JP466, JP467, JP468, JP469, JP470, JP471, JP472, JP473, JP474, JP475, JP476, JP477, JP478, JP479, JP480, JP481, JP482, JP483, JP484, JP485, JP486, JP487, JP488, JP489, JP490, JP491, JP492, JP493, JP494, JP495, JP496, JP497, JP498, JP499, JP500, JP501, JP502, JP503, JP504, JP505, JP506, JP507, JP508, JP509, JP510, JP511, JP512, JP513, JP514, JP515, JP516, JP517, JP518, JP519, JP520, JP521, JP522, JP523, JP524, JP525, JP526, JP527, JP528, JP529, JP530, JP531, JP532, JP533, JP534, JP535, JP536, JP537, JP538, JP539, JP540, JP541, JP542, JP543, JP544, JP545, JP546, JP547, JP548, JP549, JP550, JP551, JP552, JP553, JP554, JP555, JP556, JP557, JP558, JP559, JP560, JP561, JP562, JP563, JP564, JP565, JP566, JP567, JP568, JP569, JP570, JP571, JP572, JP573, JP574, JP575, JP576, JP577, JP578, JP579, JP580, JP581, JP582, JP583, JP584, JP585, JP586, JP587, JP588, JP589, JP590, JP591, JP592, JP593, JP594, JP595, JP596, JP597, JP598, JP599, JP600, JP601, JP602, JP603, JP604, JP605, JP606, JP607, JP608, JP609, JP610, JP611, JP612, JP613, JP614, JP615, JP616, JP617, JP618, JP619, JP620, JP621, JP622, JP623, JP624, JP625, JP626, JP627, JP628, JP629, JP630, JP631, JP632, JP633, JP634, JP635, JP636, JP637, JP638, JP639, JP640, JP641, JP642, JP643, JP644, JP645, JP646, JP647, JP648, JP649, JP650, JP651, JP652, JP653, JP654, JP655, JP656, JP657, JP658, JP659, JP660: 1X01
JP3: 2X20
JP4: 2X10
JP94: 2X05
JP95: 2X04
X1: AUX1; SJ1-352XN

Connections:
/CS2: JP1.4, JP3.7, JP3.8
/RD: JP1.14, JP3.27, JP3.28
/RES: JP1.2, JP3.3, JP3.4
/WR: JP1.15, JP3.29, JP3.30
A0: JP1.19, JP3.37, JP3.38
A1: JP1.18, JP3.35, JP3.36
A2: JP1.17, JP3.33, JP3.34
A3: JP1.16, JP3.31, JP3.32
CLK: JP1.13, JP3.25, JP3.26
CS1: JP1.3, JP3.5, JP3.6
D0: JP1.12, JP3.23, JP3.24
D1: JP1.11, JP3.21, JP3.22
D2: JP1.10, JP3.19, JP3.20
D3: JP1.9, JP3.17, JP3.18
D4: JP1.8, JP3.15, JP3.16
D5: JP1.7, JP3.13, JP3.14
D6: JP1.6, JP3.11, JP3.12
D7: JP1.5, JP3.9, JP3.10
GND: JP1.20, JP2.1, JP3.39, JP3.40, JP9.1, JP10.1, JP11.1, JP12.1, JP13.1, JP14.1, JP15.1, JP16.1, JP17.1, JP18.1, JP19.1, JP20.1, JP21.1, JP22.1, JP23.1, JP24.1, JP26.1, JP27.1, JP28.1, JP29.1, JP30.1, JP31.1, JP32.1, JP33.1, JP69.1, JP70.1, JP71.1, JP72.1, JP73.1, JP74.1, JP75.1, JP76.1, JP77.1, JP78.1, JP79.1, JP80.1, JP81.1, JP82.1, JP83.1, JP84.1, JP85.1, JP86.1, JP87.1, JP88.1, JP89.1, JP90.1, JP91.1, JP92.1, JP93.1, JP96.1, JP97.1, JP98.1, JP140.1, JP141.1, JP142.1, JP143.1, JP144.1, JP145.1, JP146.1, JP147.1, JP148.1, JP149.1, JP150.1, JP151.1, JP152.1, JP153.1, JP154.1, JP155.1, JP156.1, JP157.1, JP158.1, JP159.1, JP160.1, JP161.1, JP162.1, JP163.1, JP164.1, JP165.1, JP166.1, JP167.1, JP168.1
unnamed: C7.-, JP95.3, JP95.4, X1.2, X1.10
unnamed: JP95.5, JP95.6, X1.3, X1.11
unnamed: JP95.7, JP95.8, X1.1
unnamed: C7.+, JP95.1, JP95.2
unnamed: JP103.1, JP104.1, JP105.1, JP106.1
unnamed: JP4.17, JP4.18, JP94.7
unnamed: JP4.15, JP4.16, JP94.5
unnamed: JP4.13, JP4.14, JP94.3
unnamed: JP4.11, JP4.12, JP94.1
unnamed: JP4.9, JP4.10, JP94.2
unnamed: JP4.7, JP4.8, JP94.4
unnamed: JP4.5, JP4.6, JP94.6
unnamed: JP4.3, JP4.4, JP94.8
unnamed: JP5.1, JP6.1, JP7.1, JP8.1
unnamed: JP59.1, JP60.1, JP61.1, JP62.1
unnamed: JP4.1, JP4.2, JP94.10
unnamed: JP4.19, JP4.20, JP94.9
unnamed: JP107.1, JP108.1, JP109.1, JP110.1
unnamed: JP63.1, JP64.1, JP65.1, JP66.1
unnamed: JP67.1, JP68.1, JP169.1, JP170.1
unnamed: JP178.1, JP179.1, JP180.1, JP181.1
unnamed: JP182.1, JP183.1, JP184.1, JP185.1
unnamed: JP186.1, JP187.1, JP188.1, JP189.1
unnamed: JP190.1, JP191.1, JP192.1, JP193.1
unnamed: JP194.1, JP195.1, JP196.1, JP197.1
unnamed: JP198.1, JP199.1, JP200.1, JP201.1
unnamed: JP202.1, JP203.1, JP204.1, JP205.1
unnamed: JP206.1, JP207.1, JP208.1, JP209.1
unnamed: JP210.1, JP211.1, JP212.1, JP213.1
unnamed: JP214.1, JP215.1, JP216.1, JP217.1
unnamed: JP218.1, JP219.1, JP220.1, JP221.1
unnamed: JP222.1, JP223.1, JP224.1, JP225.1
unnamed: JP226.1, JP227.1, JP228.1, JP229.1
unnamed: JP230.1, JP231.1, JP232.1, JP233.1
unnamed: JP234.1, JP235.1, JP236.1, JP237.1
unnamed: JP238.1, JP239.1, JP240.1, JP241.1
unnamed: JP242.1, JP243.1, JP244.1, JP245.1
unnamed: JP246.1, JP247.1, JP248.1, JP249.1
unnamed: JP250.1, JP251.1, JP252.1, JP253.1
unnamed: JP254.1, JP255.1, JP256.1, JP257.1
unnamed: JP258.1, JP259.1, JP260.1, JP261.1
unnamed: JP262.1, JP263.1, JP264.1, JP265.1
unnamed: JP266.1, JP267.1, JP268.1, JP269.1
unnamed: JP270.1, JP271.1, JP272.1, JP273.1
unnamed: JP274.1, JP275.1, JP276.1, JP277.1
unnamed: JP278.1, JP279.1, JP280.1, JP281.1
unnamed: JP282.1, JP283.1, JP284.1, JP285.1
unnamed: JP286.1, JP287.1, JP288.1, JP289.1
unnamed: JP290.1, JP291.1, JP292.1, JP293.1
unnamed: JP294.1, JP295.1, JP296.1, JP297.1
unnamed: JP298.1, JP299.1, JP300.1, JP301.1
unnamed: JP302.1, JP303.1, JP304.1, JP305.1
unnamed: JP306.1, JP307.1, JP308.1, JP309.1
unnamed: JP310.1, JP311.1, JP312.1, JP313.1
unnamed: JP314.1, JP315.1, JP316.1, JP317.1
unnamed: JP318.1, JP319.1, JP320.1, JP321.1
unnamed: JP322.1, JP323.1, JP324.1, JP325.1
unnamed: JP326.1, JP327.1, JP328.1, JP329.1
unnamed: JP330.1, JP331.1, JP332.1, JP333.1
unnamed: JP334.1, JP335.1, JP336.1, JP337.1
unnamed: JP338.1, JP339.1, JP340.1, JP341.1
unnamed: JP342.1, JP343.1, JP344.1, JP345.1
unnamed: JP346.1, JP347.1, JP348.1, JP349.1
unnamed: JP350.1, JP351.1, JP352.1, JP353.1
unnamed: JP354.1, JP355.1, JP356.1, JP357.1
unnamed: JP358.1, JP359.1, JP360.1, JP361.1
unnamed: JP362.1, JP363.1, JP364.1, JP365.1
unnamed: JP366.1, JP367.1, JP368.1, JP369.1
unnamed: JP370.1, JP371.1, JP372.1, JP373.1
unnamed: JP374.1, JP375.1, JP376.1, JP377.1
unnamed: JP378.1, JP379.1, JP380.1, JP381.1
unnamed: JP382.1, JP383.1, JP384.1, JP385.1
unnamed: JP386.1, JP387.1, JP388.1, JP389.1
unnamed: JP390.1, JP391.1, JP392.1, JP393.1
unnamed: JP394.1, JP395.1, JP396.1, JP397.1
unnamed: JP398.1, JP399.1, JP400.1, JP401.1
unnamed: JP402.1, JP403.1, JP404.1, JP405.1
unnamed: JP406.1, JP407.1, JP408.1, JP409.1
unnamed: JP410.1, JP411.1, JP412.1, JP413.1
unnamed: JP414.1, JP415.1, JP416.1, JP417.1
unnamed: JP418.1, JP419.1, JP420.1, JP421.1
unnamed: JP422.1, JP423.1, JP424.1, JP425.1
unnamed: JP426.1, JP427.1, JP428.1, JP429.1
unnamed: JP430.1, JP431.1, JP432.1, JP433.1
unnamed: JP434.1, JP435.1, JP436.1, JP437.1
unnamed: JP438.1, JP439.1, JP440.1, JP441.1
unnamed: JP442.1, JP443.1, JP444.1, JP445.1
unnamed: JP446.1, JP447.1, JP448.1, JP449.1
unnamed: JP450.1, JP451.1, JP452.1, JP453.1
unnamed: JP454.1, JP455.1, JP456.1, JP457.1
unnamed: JP458.1, JP459.1, JP460.1, JP461.1
unnamed: JP462.1, JP463.1, JP464.1, JP465.1
unnamed: JP466.1, JP467.1, JP468.1, JP469.1
unnamed: JP470.1, JP471.1, JP472.1, JP473.1
unnamed: JP474.1, JP475.1, JP476.1, JP477.1
unnamed: JP478.1, JP479.1, JP480.1, JP481.1
unnamed: JP482.1, JP483.1, JP484.1, JP485.1
unnamed: JP486.1, JP487.1, JP488.1, JP489.1
unnamed: JP490.1, JP491.1, JP492.1, JP493.1
unnamed: JP494.1, JP495.1, JP496.1, JP497.1
unnamed: JP498.1, JP499.1, JP500.1, JP501.1
unnamed: JP502.1, JP503.1, JP504.1, JP505.1
unnamed: JP549.1, JP550.1, JP551.1, JP552.1
unnamed: JP553.1, JP554.1, JP555.1, JP556.1
unnamed: JP557.1, JP558.1, JP559.1, JP560.1
unnamed: JP561.1, JP562.1, JP563.1, JP564.1
unnamed: JP565.1, JP566.1, JP567.1, JP568.1
unnamed: JP569.1, JP570.1, JP571.1, JP572.1
unnamed: JP573.1, JP574.1, JP575.1, JP576.1
unnamed: JP577.1, JP578.1, JP579.1, JP580.1
unnamed: JP581.1, JP582.1, JP583.1, JP584.1
unnamed: JP585.1, JP586.1, JP587.1, JP588.1
unnamed: JP589.1, JP590.1, JP591.1, JP592.1
unnamed: JP593.1, JP594.1, JP595.1, JP596.1
unnamed: JP597.1, JP598.1, JP599.1, JP600.1
unnamed: JP601.1, JP602.1, JP603.1, JP604.1
unnamed: JP605.1, JP606.1, JP607.1, JP608.1
unnamed: JP609.1, JP610.1, JP611.1, JP612.1
unnamed: JP613.1, JP614.1, JP615.1, JP616.1
unnamed: JP617.1, JP618.1, JP619.1, JP620.1
unnamed: JP621.1, JP622.1, JP623.1, JP624.1
unnamed: JP625.1, JP626.1, JP627.1, JP628.1
unnamed: JP629.1, JP630.1, JP631.1, JP632.1
unnamed: JP633.1, JP634.1, JP635.1, JP636.1
unnamed: JP637.1, JP638.1, JP639.1, JP640.1
unnamed: JP641.1, JP642.1, JP643.1, JP644.1
unnamed: JP645.1, JP646.1, JP647.1, JP648.1
unnamed: JP649.1, JP650.1, JP651.1, JP652.1
unnamed: JP653.1, JP654.1, JP655.1, JP656.1
unnamed: JP657.1, JP658.1, JP659.1, JP660.1
VCC: JP1.1, JP3.1, JP3.2, JP34.1, JP35.1, JP36.1, JP37.1, JP38.1, JP39.1, JP40.1, JP41.1, JP42.1, JP43.1, JP44.1, JP45.1, JP46.1, JP47.1, JP48.1, JP49.1, JP50.1, JP51.1, JP52.1, JP53.1, JP54.1, JP55.1, JP56.1, JP57.1, JP58.1, JP99.1, JP100.1, JP101.1, JP102.1, JP111.1, JP112.1, JP113.1, JP114.1, JP115.1, JP116.1, JP117.1, JP118.1, JP119.1, JP120.1, JP121.1, JP122.1, JP123.1, JP124.1, JP125.1, JP126.1, JP127.1, JP128.1, JP129.1, JP130.1, JP131.1, JP132.1, JP133.1, JP134.1, JP135.1, JP136.1, JP137.1, JP138.1, JP139.1

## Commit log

2024-04-02 first things added
    [2048-sprites.xlsx, sn76489-simple-sound.sch, sprites-loderunner.xlsx]
2024-04-07 added test 82c55
    [io-test-8255.sch]
2024-05-11 added first test board
    [20240311-sn76489-ver1.brd, 20240311-sn76489-ver1.sch]
2024-05-12 added BusExpansion
    [PCBprototyp-Rev3-m.brd, PCBprototyp-Rev3.brd, PCBprototyp-Rev3.sch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]
2024-06-02 the next version of an extension
    [20240511-sn76489-kempton-ver1.brd, 20240511-sn76489-kempton-ver1.sch]
2024-06-16 new expansion with sd card
    [expansion-sn76489-kempton-sd-rev4.brd, expansion-sn76489-kempton-sd-rev4.sch]
2024-07-20 Improved optics labeling PCB
    [expansion-sn76489-kempton-sd-rev4b.brd, expansion-sn76489-kempton-sd-rev4b.sch]
